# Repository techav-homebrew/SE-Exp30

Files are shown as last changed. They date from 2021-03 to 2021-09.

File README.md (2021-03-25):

# SE-Exp30 Mac SE Accelerator
Minimal 68030 &amp; 68882 accelerator card for the Macintosh SE

This project is not intended to be the fastest or most feature-rich accelerator for the Mac SE. Its primary goal is to be simple and transparent to Mac OS. Without the FPU, it should be able to function as just a faster Mac SE. To make full use of the FPU and the 68030's onboard cache, MacOS may need an init or extension to enable these features and advertise their presence to applications. 

The glue logic is entirely contained in a single 64-macrocel CPLD. Either an Altera EPM7064 or an Atmel ATF1504 will work. It is programmed and compiled for the Altera chip, but tested with the Atmel chip, using the free POF2JED software to convert the compiled configuration to the Atmel format. 

Should the initial design prove successful, future revisions may add cache or RAM on a 32-bit bus to further accelerate the SE. 

## Bill of Materials
Parts count is minimal
- Motorola 68030 CPU (MC68030RC or MC68030RP)
- Motorola 68882 FPU (MC68882RC)
- Microchip/Atmel ATF1504AS-10JU84 (PLLC-84)
- 7x 74'245 buffers (SOIC-20)
- 2x 10uF Electrolyic capacitors (5mm, 2.5mm lead spacing)
- 33x 1uF Ceramic capacitors (0805)
- 16x 4k7 resistors (0805)
- TTL Crystal Oscillator (DIP-8)
- DIN 41612-C 96-pin right-angle connector (male)
- optional 4-pin floppy/Berg power connector

None of the part values are especially critical. The oscillator frequency should match the intended CPU/FPU speed, and the speed grade for the CPLD should be appropriate for the target speed as well. Timing for the CPLD was planned with a 10ns CPLD and 50MHz CPU in mind. As the 68030 CPU and 68882 FPU are no longer produced, it is left to the reader to source these parts and determine the appropriate oscillator frequency to use with whatever parts are available. Processors were originally offered in 16MHz, 20MHz, 25MHz, 33MHz, 40MHz, and 50MHz ratings. It may be necessary to convert the PCB to 4-layers and insert internal power/ground planes to achieve higher clock rates. 

All capacitors on the BOM are included for bypass/filter purposes, so their values are not critical. Lower capacitance isn't recommended, but higher values may certainly be substituted. Similarly, the resistors only serve as pull-ups so their values are also not critical. 

## Power Supply
The Mac SE is rated to provide 7.5W on the 5V rail for PDS cards. This card may exceed that 7.5W rating. Depending on the configuration of the SE model (e.g. presence of a hard drive) and the health of the power supply, a separate 5V power supply may be necessary to power this accelerator. A footprint is provided for a 4-pin floppy (Berg) connector. If an external power supply is used, the jumpers J1, J2, J3 should be left open. If the card will be powered via the PDS slot, these jumpers should be closed, and nothing should be connected to the power connector.

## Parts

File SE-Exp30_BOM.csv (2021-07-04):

Part | Value | Device | Package | Description | Mfg | Mfg Part | Mouser Part
BUFAHI | 74VHCT245 | 74LS245DW | SOIC-20 | Octal BUS TRANSCEIVER, 3-state | Texas Instruments | CY74FCT2245ATSOCT | 595-CY74FCT2245ATOCT
BUFALO | 74VHCT245 | 74LS245DW | SOIC-20 | Octal BUS TRANSCEIVER, 3-state | Texas Instruments | CY74FCT2245ATSOCT | 595-CY74FCT2245ATOCT
BUFAMID | 74VHCT245 | 74LS245DW | SOIC-20 | Octal BUS TRANSCEIVER, 3-state | Texas Instruments | CY74FCT2245ATSOCT | 595-CY74FCT2245ATOCT
BUFC | 74VHCT245 | 74LS245DW | SOIC-20 | Octal BUS TRANSCEIVER, 3-state | Texas Instruments | CY74FCT2245ATSOCT | 595-CY74FCT2245ATOCT
BUFDHI | 74VHCT245 | 74LS245DW | SOIC-20 | Octal BUS TRANSCEIVER, 3-state | Texas Instruments | CY74FCT2245ATSOCT | 595-CY74FCT2245ATOCT
BUFDLO1 | 74VHCT245 | 74LS245DW | SOIC-20 | Octal BUS TRANSCEIVER, 3-state | Texas Instruments | CY74FCT2245ATSOCT | 595-CY74FCT2245ATOCT
BUFDLO2 | 74VHCT245 | 74LS245DW | SOIC-20 | Octal BUS TRANSCEIVER, 3-state | Texas Instruments | CY74FCT2245ATSOCT | 595-CY74FCT2245ATOCT
C1 | 1uF | C-USC0805 | C0805 | CAPACITOR, American symbol | Kemet | C0805C105Z4VACTU | 80-C0805C105Z4V
C2 | 1uF | C-USC0805 | C0805 | CAPACITOR, American symbol | Kemet | C0805C105Z4VACTU | 80-C0805C105Z4V
C3 | 1uF | C-USC0805 | C0805 | CAPACITOR, American symbol | Kemet | C0805C105Z4VACTU | 80-C0805C105Z4V
C4 | 1uF | C-USC0805 | C0805 | CAPACITOR, American symbol | Kemet | C0805C105Z4VACTU | 80-C0805C105Z4V
C5 | 1uF | C-USC0805 | C0805 | CAPACITOR, American symbol | Kemet | C0805C105Z4VACTU | 80-C0805C105Z4V
C6 | 1uF | C-USC0805 | C0805 | CAPACITOR, American symbol | Kemet | C0805C105Z4VACTU | 80-C0805C105Z4V
C7 | 1uF | C-USC0805 | C0805 | CAPACITOR, American symbol | Kemet | C0805C105Z4VACTU | 80-C0805C105Z4V
C8 | 1uF | C-USC0805 | C0805 | CAPACITOR, American symbol | Kemet | C0805C105Z4VACTU | 80-C0805C105Z4V
C9 | 1uF | C-USC0805 | C0805 | CAPACITOR, American symbol | Kemet | C0805C105Z4VACTU | 80-C0805C105Z4V
C10 | 1uF | C-USC0805 | C0805 | CAPACITOR, American symbol | Kemet | C0805C105Z4VACTU | 80-C0805C105Z4V
C11 | 1uF | C-USC0805 | C0805 | CAPACITOR, American symbol | Kemet | C0805C105Z4VACTU | 80-C0805C105Z4V
C12 | 1uF | C-USC0805 | C0805 | CAPACITOR, American symbol | Kemet | C0805C105Z4VACTU | 80-C0805C105Z4V
C13 | 1uF | C-USC0805 | C0805 | CAPACITOR, American symbol | Kemet | C0805C105Z4VACTU | 80-C0805C105Z4V
C14 | 1uF | C-USC0805 | C0805 | CAPACITOR, American symbol | Kemet | C0805C105Z4VACTU | 80-C0805C105Z4V
C15 | 1uF | C-USC0805 | C0805 | CAPACITOR, American symbol | Kemet | C0805C105Z4VACTU | 80-C0805C105Z4V
C16 | 1uF | C-USC0805 | C0805 | CAPACITOR, American symbol | Kemet | C0805C105Z4VACTU | 80-C0805C105Z4V
C17 | 1uF | C-USC0805 | C0805 | CAPACITOR, American symbol | Kemet | C0805C105Z4VACTU | 80-C0805C105Z4V
C18 | 1uF | C-USC0805 | C0805 | CAPACITOR, American symbol | Kemet | C0805C105Z4VACTU | 80-C0805C105Z4V
C19 | 1uF | C-USC0805 | C0805 | CAPACITOR, American symbol | Kemet | C0805C105Z4VACTU | 80-C0805C105Z4V
C20 | 1uF | C-USC0805 | C0805 | CAPACITOR, American symbol | Kemet | C0805C105Z4VACTU | 80-C0805C105Z4V
C21 | 1uF | C-USC0805 | C0805 | CAPACITOR, American symbol | Kemet | C0805C105Z4VACTU | 80-C0805C105Z4V
C22 | 1uF | C-USC0805 | C0805 | CAPACITOR, American symbol | Kemet | C0805C105Z4VACTU | 80-C0805C105Z4V
C23 | 1uF | C-USC0805 | C0805 | CAPACITOR, American symbol | Kemet | C0805C105Z4VACTU | 80-C0805C105Z4V
C24 | 1uF | C-USC0805 | C0805 | CAPACITOR, American symbol | Kemet | C0805C105Z4VACTU | 80-C0805C105Z4V
C25 | 1uF | C-USC0805 | C0805 | CAPACITOR, American symbol | Kemet | C0805C105Z4VACTU | 80-C0805C105Z4V
C26 | 1uF | C-USC0805 | C0805 | CAPACITOR, American symbol | Kemet | C0805C105Z4VACTU | 80-C0805C105Z4V
C27 | 10uF | CPOL-USE2.5-5 | E2,5-5 | POLARIZED CAPACITOR, American symbol | Panasonic | ECA-1EM100I | 667-ECA-1EM100I
C28 | 10uF | CPOL-USE2.5-5 | E2,5-5 | POLARIZED CAPACITOR, American symbol | Panasonic | ECA-1EM100I | 667-ECA-1EM100I
C29 | 1uF | C-USC0805 | C0805 | CAPACITOR, American symbol | Kemet | C0805C105Z4VACTU | 80-C0805C105Z4V
C30 | 1uF | C-USC0805 | C0805 | CAPACITOR, American symbol | Kemet | C0805C105Z4VACTU | 80-C0805C105Z4V
C31 | 1uF | C-USC0805 | C0805 | CAPACITOR, American symbol | Kemet | C0805C105Z4VACTU | 80-C0805C105Z4V
C32 | 1uF | C-USC0805 | C0805 | CAPACITOR, American symbol | Kemet | C0805C105Z4VACTU | 80-C0805C105Z4V
C33 | 1uF | C-USC0805 | C0805 | CAPACITOR, American symbol | Kemet | C0805C105Z4VACTU | 80-C0805C105Z4V
C34 | 1uF | C-USC0805 | C0805 | CAPACITOR, American symbol | Kemet | C0805C105Z4VACTU | 80-C0805C105Z4V
C35 | 1uF | C-USC0805 | C0805 | CAPACITOR, American symbol | Kemet | C0805C105Z4VACTU | 80-C0805C105Z4V
CLOCK |  | QG5460 | DIL08S | CRYSTAL RESONATOR
CPU | 68030 | MC68030RC | MPGA128 | 68xxx PROCESSOR | Motorola | MC68030RCxx
FPU | 68882 | MC68881RC | MPGA68 | 68xxx PROCESSOR | Motorola | MC68882RCxx
JP1 |  | JP1Q | JP1 | JUMPER
JP2 |  | JP1Q | JP1 | JUMPER
JP3 |  | JP1Q | JP1 | JUMPER
PASTE | ATF1504AS | EPM7128-J84S | S84 | EPM70128 | Microchip | ATF1504AS-10JU84 | 556-AF1504AS10JU84
POWER |  | L04P | L04P | AMP MT CONNECTOR | TE Connectivity | 171826-4 | 571-1718264
R1 | 4k7 | R-US_R0805 | R0805 | RESISTOR, American symbol | Vishay | CRCW08054K70JNEAC | 71-CRCW08054K70JNEAC
R2 | 4k7 | R-US_R0805 | R0805 | RESISTOR, American symbol | Vishay | CRCW08054K70JNEAC | 71-CRCW08054K70JNEAC
R3 | 4k7 | R-US_R0805 | R0805 | RESISTOR, American symbol | Vishay | CRCW08054K70JNEAC | 71-CRCW08054K70JNEAC
R4 | 4k7 | R-US_R0805 | R0805 | RESISTOR, American symbol | Vishay | CRCW08054K70JNEAC | 71-CRCW08054K70JNEAC
R5 | 4k7 | R-US_R0805 | R0805 | RESISTOR, American symbol | Vishay | CRCW08054K70JNEAC | 71-CRCW08054K70JNEAC
R6 | 4k7 | R-US_R0805 | R0805 | RESISTOR, American symbol | Vishay | CRCW08054K70JNEAC | 71-CRCW08054K70JNEAC
R7 | 4k7 | R-US_R0805 | R0805 | RESISTOR, American symbol | Vishay | CRCW08054K70JNEAC | 71-CRCW08054K70JNEAC
R8 | 4k7 | R-US_R0805 | R0805 | RESISTOR, American symbol | Vishay | CRCW08054K70JNEAC | 71-CRCW08054K70JNEAC
R9 | 4k7 | R-US_R0805 | R0805 | RESISTOR, American symbol | Vishay | CRCW08054K70JNEAC | 71-CRCW08054K70JNEAC
R10 | 4k7 | R-US_R0805 | R0805 | RESISTOR, American symbol | Vishay | CRCW08054K70JNEAC | 71-CRCW08054K70JNEAC
R11 | 4k7 | R-US_R0805 | R0805 | RESISTOR, American symbol | Vishay | CRCW08054K70JNEAC | 71-CRCW08054K70JNEAC
R12 | 4k7 | R-US_R0805 | R0805 | RESISTOR, American symbol | Vishay | CRCW08054K70JNEAC | 71-CRCW08054K70JNEAC
R13 | 4k7 | R-US_R0805 | R0805 | RESISTOR, American symbol | Vishay | CRCW08054K70JNEAC | 71-CRCW08054K70JNEAC
R14 | 4k7 | R-US_R0805 | R0805 | RESISTOR, American symbol | Vishay | CRCW08054K70JNEAC | 71-CRCW08054K70JNEAC
R15 | 4k7 | R-US_R0805 | R0805 | RESISTOR, American symbol | Vishay | CRCW08054K70JNEAC | 71-CRCW08054K70JNEAC
R16 | 4k7 | R-US_R0805 | R0805 | RESISTOR, American symbol | Vishay | CRCW08054K70JNEAC | 71-CRCW08054K70JNEAC
X1 | MABC96LP | MABC96LP | MABC96LP | CONNECTOR male, 96 pins, type C, rows ABC, grid 2.54 mm with mounting clip | TE Connectivity | 650473-5 | 571-6504735

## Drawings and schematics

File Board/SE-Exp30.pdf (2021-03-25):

CLK E01 | D0 K13 | D1 K12 | D2 L13 | D3 M13 | D4 L12 | D5 K11 | D6 M12 | D7 L11 | D8 N13 | D9 M11 | D10 L10 | D11 N12 | D12 M10 | D13 N11 | D14 M09 | D15 N10 | D16 N09 | D17 M08 | D18 N08 | D19 N07 | D20 M07 | D21 N06 | D22 M06 | D23 N05 | D24 M05 | D25 N04 | D26 N03 | D27 M04 | D28 N02 | D29 M03 | D30 L04 | D31 N01
A0 | H03 A1 | K01 A2 | H02 A3 | J01 A4 | G02 AS H01 | CLK C02 | CS J03 | D0 A03 | D1 A04 | D2 B05 | D3 A05 | D4 A06 | D5 B06 | D6 A07 | D7 A08 | D8 A09 | D9 C08 | D10 B09 | D11 B10 | D12 D09 | D13 C09 | D14 C10 | D15 D10 | D16 F10 | D17 F09 | D18 G10 | D19 H10 | D20 G09 | D21 J10 | D22 K10 | D23 J09 | D24 K09 | D25 J07 | D26 K08 | D27 K07 | D28 J06 | D29 K06 | D30 K05 | D31 J05

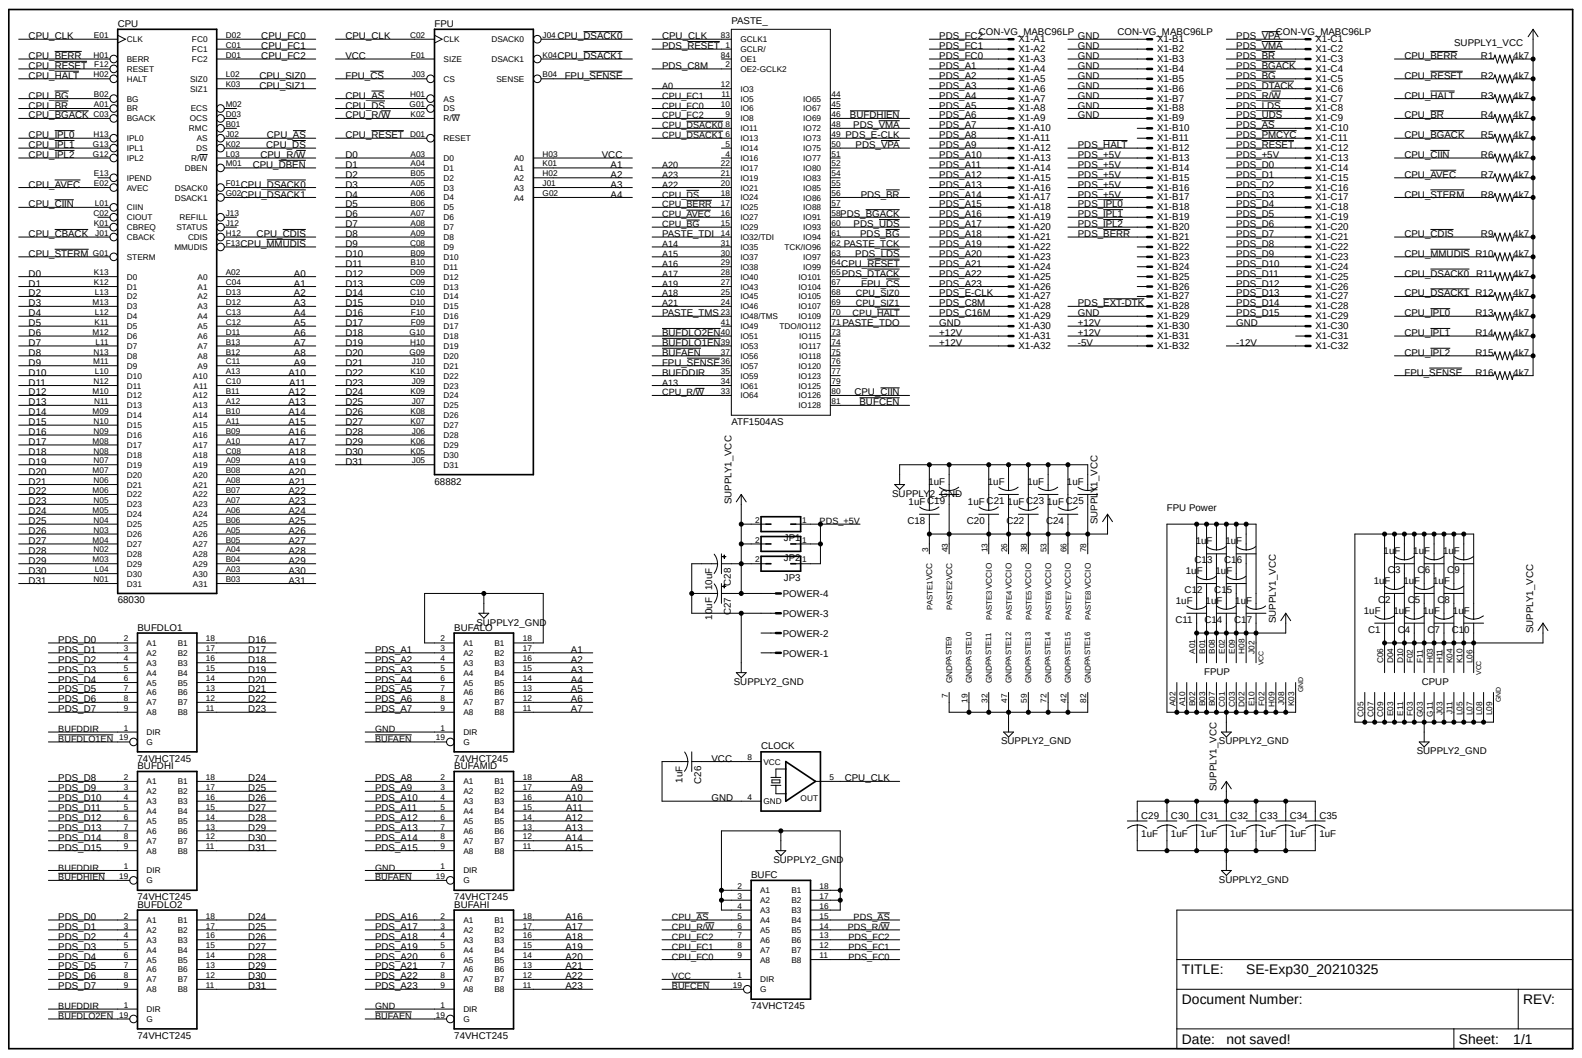
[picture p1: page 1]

3 PASTE1VCC 43 PASTE2VCCIO 13 PASTE3 VCCIO 26 PASTE4 VCCIO 38 PASTE5 VCCIO 53 PASTE6 VCCIO 66 PASTE7 VCCIO 78 PASTE8 GND

7 PASTE9 GND 19 PASTE10 GND 32 PASTE11 GND 47 PASTE12 GND 59 PASTE13 GND 72 PASTE14 GND 42 PASTE15 GND 82 PASTE16 A1 2 A2 3 A3 4 A4 5 A5 6 A6 7 A7 8 A8 9 B1 18 B2 17 B3 16 B4 15 B5 14 B6 13 B7 12 B8 11 DIR 1 G

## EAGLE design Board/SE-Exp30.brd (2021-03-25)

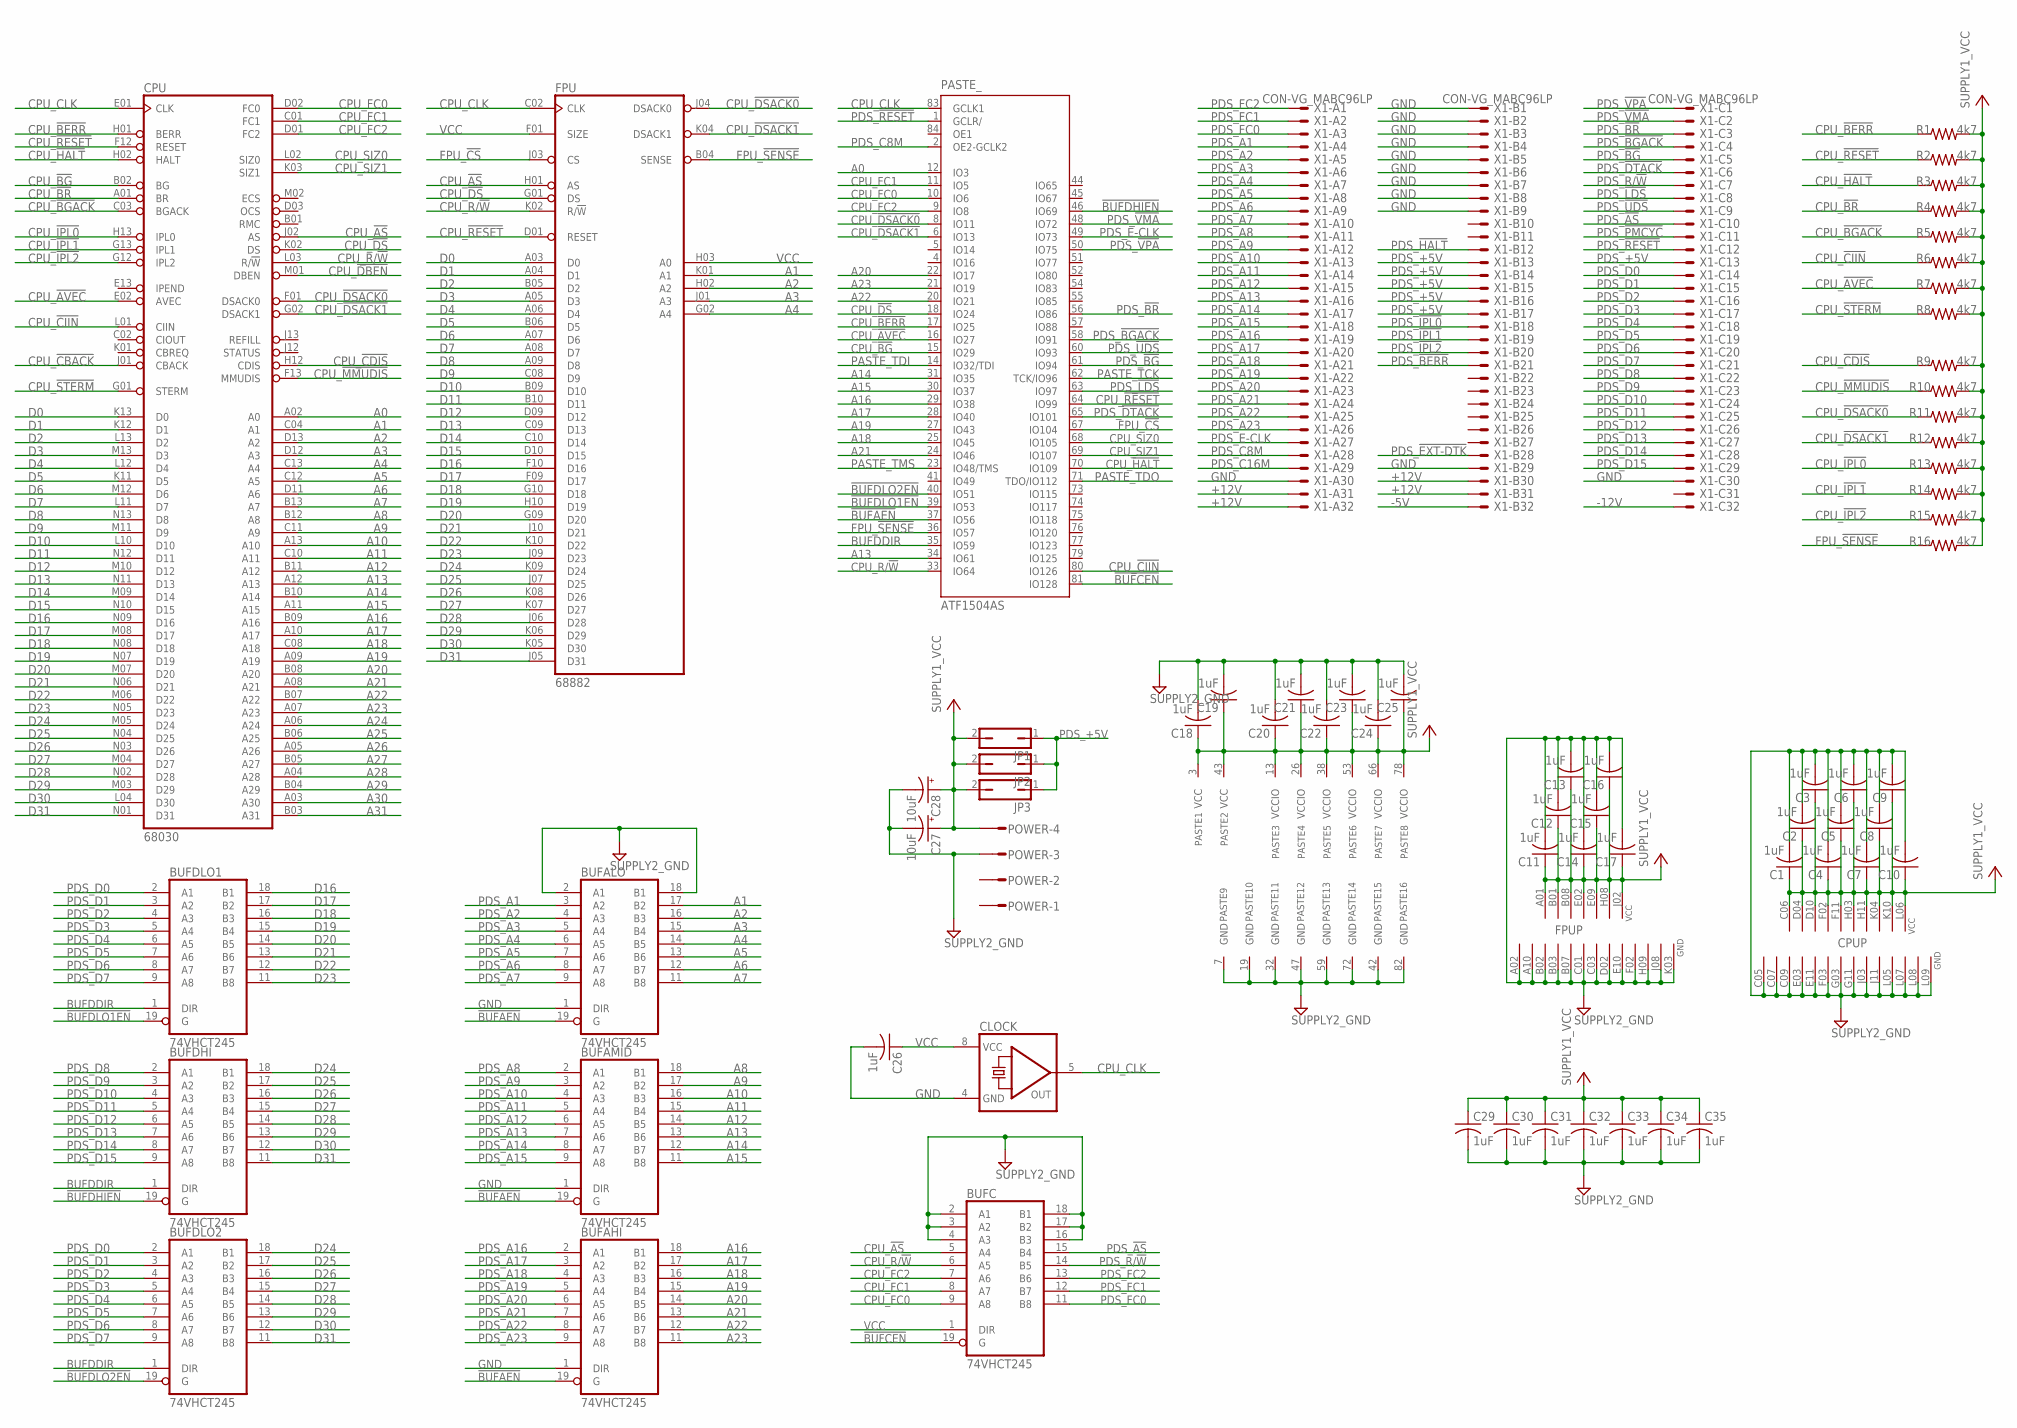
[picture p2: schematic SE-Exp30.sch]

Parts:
BUFAHI: 74VHCT245; 74XX-US_SO20W
BUFALO: 74VHCT245; 74XX-US_SO20W
BUFAMID: 74VHCT245; 74XX-US_SO20W
BUFC: 74VHCT245; 74XX-US_SO20W
BUFDHI: 74VHCT245; 74XX-US_SO20W
BUFDLO1, BUFDLO2: 74VHCT245; 74XX-US_SO20W
C1, C2, C3, C4, C5, C6, C7, C8, C9, C10, C11, C12, C13, C14, C15, C16, C17, C18, C19, C20, C21, C22, C23, C24, C25, C26, C29, C30, C31, C32, C33, C34, C35: 1uF; RCL_C0805
C27, C28: 10uF; RCL_E2,5-5
CLOCK: CRYSTAL_QG5460; CRYSTAL_DIL08S
CPU: 68030; MICRO-MC68000_MPGA128
FPU: 68882; MICRO-MC68000_MPGA68
JP1, JP2, JP3: JUMPER_JP1Q; JUMPER_JP1
PASTE: ATF1504AS; SE-EXP30_S84
POWER: CON-AMP-MT_L04P
R1, R2, R3, R4, R5, R6, R7, R8, R9, R10, R11, R12, R13, R14, R15, R16: 4k7; RCL_R0805
X1: CON-VG_MABC96LP

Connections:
!BUFAEN: BUFAHI.19 (G), BUFALO.19 (G), BUFAMID.19 (G), PASTE.37 (IO56)
!BUFCEN: BUFC.19 (G), PASTE.81 (IO128)
!BUFDHIEN: BUFDHI.19 (G), PASTE.46 (IO69)
!BUFDLO1EN: BUFDLO1.19 (G), PASTE.39 (IO53)
!BUFDLO2EN: BUFDLO2.19 (G), PASTE.40 (IO51)
+12V: X1.A31, X1.A32, X1.B30, X1.B31
-5V: X1.B32
-12V: X1.C32
A0: CPU.A02 (A0), PASTE.12 (IO3)
A1: BUFALO.17 (B2), CPU.C04 (A1), FPU.K01 (A1)
A2: BUFALO.16 (B3), CPU.D13 (A2), FPU.H02 (A2)
A3: BUFALO.15 (B4), CPU.D12 (A3), FPU.J01 (A3)
A4: BUFALO.14 (B5), CPU.C13 (A4), FPU.G02 (A4)
A5: BUFALO.13 (B6), CPU.C12 (A5)
A6: BUFALO.12 (B7), CPU.D11 (A6)
A7: BUFALO.11 (B8), CPU.B13 (A7)
A8: BUFAMID.18 (B1), CPU.B12 (A8)
A9: BUFAMID.17 (B2), CPU.C11 (A9)
A10: BUFAMID.16 (B3), CPU.A13 (A10)
A11: BUFAMID.15 (B4), CPU.C10 (A11)
A12: BUFAMID.14 (B5), CPU.B11 (A12)
A13: BUFAMID.13 (B6), CPU.A12 (A13), PASTE.34 (IO61)
A14: BUFAMID.12 (B7), CPU.B10 (A14), PASTE.31 (IO35)
A15: BUFAMID.11 (B8), CPU.A11 (A15), PASTE.30 (IO37)
A16: BUFAHI.18 (B1), CPU.B09 (A16), PASTE.29 (IO38)
A17: BUFAHI.17 (B2), CPU.A10 (A17), PASTE.28 (IO40)
A18: BUFAHI.16 (B3), CPU.C08 (A18), PASTE.25 (IO45)
A19: BUFAHI.15 (B4), CPU.A09 (A19), PASTE.27 (IO43)
A20: BUFAHI.14 (B5), CPU.B08 (A20), PASTE.22 (IO17)
A21: BUFAHI.13 (B6), CPU.A08 (A21), PASTE.24 (IO46)
A22: BUFAHI.12 (B7), CPU.B07 (A22), PASTE.20 (IO21)
A23: BUFAHI.11 (B8), CPU.A07 (A23), PASTE.21 (IO19)
A24: CPU.A06 (A24)
A25: CPU.B06 (A25)
A26: CPU.A05 (A26)
A27: CPU.B05 (A27)
A28: CPU.A04 (A28)
A29: CPU.B04 (A29)
A30: CPU.A03 (A30)
A31: CPU.B03 (A31)
BUFDDIR: BUFDHI.1 (DIR), BUFDLO1.1 (DIR), BUFDLO2.1 (DIR), PASTE.35 (IO59)
CPU_!AS: BUFC.5 (A4), CPU.J02 (AS), FPU.H01 (AS)
CPU_!AVEC: CPU.E02 (AVEC), PASTE.16 (IO27), R7.1
CPU_!BERR: CPU.H01 (BERR), PASTE.17 (IO25), R1.1
CPU_!BG: CPU.B02 (BG), PASTE.15 (IO29)
CPU_!BGACK: CPU.C03 (BGACK), R5.1
CPU_!BR: CPU.A01 (BR), R4.1
CPU_!CBACK: CPU.J01 (CBACK)
CPU_!CDIS: CPU.H12 (CDIS), R9.1
CPU_!CIIN: CPU.L01 (CIIN), PASTE.80 (IO126), R6.1
CPU_!DBEN: CPU.M01 (DBEN)
CPU_!DS: CPU.K02 (DS), FPU.G01 (DS), PASTE.18 (IO24)
CPU_!DSACK0: CPU.F01 (DSACK0), FPU.J04 (DSACK0), PASTE.8 (IO11), R11.1
CPU_!DSACK1: CPU.G02 (DSACK1), FPU.K04 (DSACK1), PASTE.6 (IO13), R12.1
CPU_!HALT: CPU.H02 (HALT), PASTE.70 (IO109), R3.1
CPU_!IPL0: CPU.H13 (IPL0), R13.1
CPU_!IPL1: CPU.G13 (IPL1), R14.1
CPU_!IPL2: CPU.G12 (IPL2), R15.1
CPU_!MMUDIS: CPU.F13 (MMUDIS), R10.1
CPU_!RESET: CPU.F12 (RESET), FPU.D01 (RESET), PASTE.64 (IO99), R2.1
CPU_!STERM: CPU.G01 (STERM), R8.1
CPU_CLK: CLOCK.5 (OUT), CPU.E01 (CLK), FPU.C02 (CLK), PASTE.83 (GCLK1)
CPU_FC0: BUFC.9 (A8), CPU.D02 (FC0), PASTE.10 (IO6)
CPU_FC1: BUFC.8 (A7), CPU.C01 (FC1), PASTE.11 (IO5)
CPU_FC2: BUFC.7 (A6), CPU.D01 (FC2), PASTE.9 (IO8)
CPU_R/!W: BUFC.6 (A5), CPU.L03 (R/!W), FPU.K02 (R/!W), PASTE.33 (IO64)
CPU_SIZ0: CPU.L02 (SIZ0), PASTE.68 (IO105)
CPU_SIZ1: CPU.K03 (SIZ1), PASTE.69 (IO107)
D0: CPU.K13 (D0), FPU.A03 (D0)
D1: CPU.K12 (D1), FPU.A04 (D1)
D2: CPU.L13 (D2), FPU.B05 (D2)
D3: CPU.M13 (D3), FPU.A05 (D3)
D4: CPU.L12 (D4), FPU.A06 (D4)
D5: CPU.K11 (D5), FPU.B06 (D5)
D6: CPU.M12 (D6), FPU.A07 (D6)
D7: CPU.L11 (D7), FPU.A08 (D7)
D8: CPU.N13 (D8), FPU.A09 (D8)
D9: CPU.M11 (D9), FPU.C08 (D9)
D10: CPU.L10 (D10), FPU.B09 (D10)
D11: CPU.N12 (D11), FPU.B10 (D11)
D12: CPU.M10 (D12), FPU.D09 (D12)
D13: CPU.N11 (D13), FPU.C09 (D13)
D14: CPU.M09 (D14), FPU.C10 (D14)
D15: CPU.N10 (D15), FPU.D10 (D15)
D16: BUFDLO1.18 (B1), CPU.N09 (D16), FPU.F10 (D16)
D17: BUFDLO1.17 (B2), CPU.M08 (D17), FPU.F09 (D17)
D18: BUFDLO1.16 (B3), CPU.N08 (D18), FPU.G10 (D18)
D19: BUFDLO1.15 (B4), CPU.N07 (D19), FPU.H10 (D19)
D20: BUFDLO1.14 (B5), CPU.M07 (D20), FPU.G09 (D20)
D21: BUFDLO1.13 (B6), CPU.N06 (D21), FPU.J10 (D21)
D22: BUFDLO1.12 (B7), CPU.M06 (D22), FPU.K10 (D22)
D23: BUFDLO1.11 (B8), CPU.N05 (D23), FPU.J09 (D23)
D24: BUFDHI.18 (B1), BUFDLO2.18 (B1), CPU.M05 (D24), FPU.K09 (D24)
D25: BUFDHI.17 (B2), BUFDLO2.17 (B2), CPU.N04 (D25), FPU.J07 (D25)
D26: BUFDHI.16 (B3), BUFDLO2.16 (B3), CPU.N03 (D26), FPU.K08 (D26)
D27: BUFDHI.15 (B4), BUFDLO2.15 (B4), CPU.M04 (D27), FPU.K07 (D27)
D28: BUFDHI.14 (B5), BUFDLO2.14 (B5), CPU.N02 (D28), FPU.J06 (D28)
D29: BUFDHI.13 (B6), BUFDLO2.13 (B6), CPU.M03 (D29), FPU.K06 (D29)
D30: BUFDHI.12 (B7), BUFDLO2.12 (B7), CPU.L04 (D30), FPU.K05 (D30)
D31: BUFDHI.11 (B8), BUFDLO2.11 (B8), CPU.N01 (D31), FPU.J05 (D31)
FPU_!CS: FPU.J03 (CS), PASTE.67 (IO104)
FPU_!SENSE: FPU.B04 (SENSE), PASTE.36 (IO57), R16.1
GND: BUFAHI.1 (DIR), BUFAHI.10 (GND), BUFALO.1 (DIR), BUFALO.2 (A1), BUFALO.10 (GND), BUFALO.18 (B1), BUFAMID.1 (DIR), BUFAMID.10 (GND), BUFC.2 (A1), BUFC.3 (A2), BUFC.4 (A3), BUFC.10 (GND), BUFC.16 (B3), BUFC.17 (B2), BUFC.18 (B1), BUFDHI.10 (GND), BUFDLO1.10 (GND), BUFDLO2.10 (GND), C1.2, C2.2, C3.2, C4.2, C5.2, C6.2, C7.2, C8.2, C9.2, C10.2, C11.2, C12.2, C13.2, C14.2, C15.2, C16.2, C17.2, C18.2, C19.2, C20.2, C21.2, C22.2, C23.2, C24.2, C25.2, C26.2, C27.-, C28.-, C29.2, C30.2, C31.2, C32.2, C33.2, C34.2, C35.2, CLOCK.4 (GND), CPU.C05 (GND), CPU.C07 (GND), CPU.C09 (GND), CPU.E03 (GND), CPU.E11 (GND), CPU.F03 (GND), CPU.G03 (GND), CPU.G11 (GND), CPU.J03 (GND), CPU.J11 (GND), CPU.L05 (GND), CPU.L07 (GND), CPU.L08 (GND), CPU.L09 (GND), FPU.A02 (GND), FPU.A10 (GND), FPU.B02 (GND), FPU.B03 (GND), FPU.B07 (GND), FPU.C01 (GND), FPU.C03 (GND), FPU.D02 (GND), FPU.E10 (GND), FPU.F02 (GND), FPU.H09 (GND), FPU.J08 (GND), FPU.K03 (GND), PASTE.7 (GND), PASTE.19 (GND), PASTE.32 (GND), PASTE.42 (GND), PASTE.47 (GND), PASTE.59 (GND), PASTE.72 (GND), PASTE.82 (GND), POWER.3, X1.A30, X1.B1, X1.B2, X1.B3, X1.B4, X1.B5, X1.B6, X1.B7, X1.B8, X1.B9, X1.B29, X1.C30
PASTE_TCK: PASTE.62 (TCK/IO96)
PASTE_TDI: PASTE.14 (IO32/TDI)
PASTE_TDO: PASTE.71 (TDO/IO112)
PASTE_TMS: PASTE.23 (IO48/TMS)
PDS_!AS: BUFC.15 (B4), X1.C10
PDS_!BERR: X1.B21
PDS_!BG: PASTE.61 (IO94), X1.C5
PDS_!BGACK: PASTE.58 (IO91), X1.C4
PDS_!BR: PASTE.56 (IO86), X1.C3
PDS_!DTACK: PASTE.65 (IO101), X1.C6
PDS_!EXT-DTK: X1.B28
PDS_!HALT: X1.B12
PDS_!IPL0: X1.B18
PDS_!IPL1: X1.B19
PDS_!IPL2: X1.B20
PDS_!LDS: PASTE.63 (IO97), X1.C8
PDS_!PMCYC: X1.C11
PDS_!RESET: PASTE.1 (GCLR/), X1.C12
PDS_!UDS: PASTE.60 (IO93), X1.C9
PDS_!VMA: PASTE.48 (IO72), X1.C2
PDS_!VPA: PASTE.50 (IO75), X1.C1
PDS_+5V: JP1.1, JP2.1, JP3.1, X1.B13, X1.B14, X1.B15, X1.B16, X1.B17, X1.C13
PDS_A1: BUFALO.3 (A2), X1.A4
PDS_A2: BUFALO.4 (A3), X1.A5
PDS_A3: BUFALO.5 (A4), X1.A6
PDS_A4: BUFALO.6 (A5), X1.A7
PDS_A5: BUFALO.7 (A6), X1.A8
PDS_A6: BUFALO.8 (A7), X1.A9
PDS_A7: BUFALO.9 (A8), X1.A10
PDS_A8: BUFAMID.2 (A1), X1.A11
PDS_A9: BUFAMID.3 (A2), X1.A12
PDS_A10: BUFAMID.4 (A3), X1.A13
PDS_A11: BUFAMID.5 (A4), X1.A14
PDS_A12: BUFAMID.6 (A5), X1.A15
PDS_A13: BUFAMID.7 (A6), X1.A16
PDS_A14: BUFAMID.8 (A7), X1.A17
PDS_A15: BUFAMID.9 (A8), X1.A18
PDS_A16: BUFAHI.2 (A1), X1.A19
PDS_A17: BUFAHI.3 (A2), X1.A20
PDS_A18: BUFAHI.4 (A3), X1.A21
PDS_A19: BUFAHI.5 (A4), X1.A22
PDS_A20: BUFAHI.6 (A5), X1.A23
PDS_A21: BUFAHI.7 (A6), X1.A24
PDS_A22: BUFAHI.8 (A7), X1.A25
PDS_A23: BUFAHI.9 (A8), X1.A26
PDS_C8M: PASTE.2 (OE2-GCLK2), X1.A28
PDS_C16M: X1.A29
PDS_D0: BUFDLO1.2 (A1), BUFDLO2.2 (A1), X1.C14
PDS_D1: BUFDLO1.3 (A2), BUFDLO2.3 (A2), X1.C15
PDS_D2: BUFDLO1.4 (A3), BUFDLO2.4 (A3), X1.C16
PDS_D3: BUFDLO1.5 (A4), BUFDLO2.5 (A4), X1.C17
PDS_D4: BUFDLO1.6 (A5), BUFDLO2.6 (A5), X1.C18
PDS_D5: BUFDLO1.7 (A6), BUFDLO2.7 (A6), X1.C19
PDS_D6: BUFDLO1.8 (A7), BUFDLO2.8 (A7), X1.C20
PDS_D7: BUFDLO1.9 (A8), BUFDLO2.9 (A8), X1.C21
PDS_D8: BUFDHI.2 (A1), X1.C22
PDS_D9: BUFDHI.3 (A2), X1.C23
PDS_D10: BUFDHI.4 (A3), X1.C24
PDS_D11: BUFDHI.5 (A4), X1.C25
PDS_D12: BUFDHI.6 (A5), X1.C26
PDS_D13: BUFDHI.7 (A6), X1.C27
PDS_D14: BUFDHI.8 (A7), X1.C28
PDS_D15: BUFDHI.9 (A8), X1.C29
PDS_E-CLK: PASTE.49 (IO73), X1.A27
PDS_FC0: BUFC.11 (B8), X1.A3
PDS_FC1: BUFC.12 (B7), X1.A2
PDS_FC2: BUFC.13 (B6), X1.A1
PDS_R/!W: BUFC.14 (B5), X1.C7
VCC: BUFAHI.20 (VCC), BUFALO.20 (VCC), BUFAMID.20 (VCC), BUFC.1 (DIR), BUFC.20 (VCC), BUFDHI.20 (VCC), BUFDLO1.20 (VCC), BUFDLO2.20 (VCC), C1.1, C2.1, C3.1, C4.1, C5.1, C6.1, C7.1, C8.1, C9.1, C10.1, C11.1, C12.1, C13.1, C14.1, C15.1, C16.1, C17.1, C18.1, C19.1, C20.1, C21.1, C22.1, C23.1, C24.1, C25.1, C26.1, C27.+, C28.+, C29.1, C30.1, C31.1, C32.1, C33.1, C34.1, C35.1, CLOCK.8 (VCC), CPU.C06 (VCC), CPU.D04 (VCC), CPU.D10 (VCC), CPU.F02 (VCC), CPU.F11 (VCC), CPU.H03 (VCC), CPU.H11 (VCC), CPU.K04 (VCC), CPU.K10 (VCC), CPU.L06 (VCC), FPU.A01 (VCC), FPU.B01 (VCC), FPU.B08 (VCC), FPU.E02 (VCC), FPU.E09 (VCC), FPU.F01 (SIZE), FPU.H03 (A0), FPU.H08 (VCC), FPU.J02 (VCC), JP1.2, JP2.2, JP3.2, PASTE.3 (VCC), PASTE.13 (VCCIO), PASTE.26 (VCCIO), PASTE.38 (VCCIO), PASTE.43 (VCC), PASTE.53 (VCCIO), PASTE.66 (VCCIO), PASTE.78 (VCCIO), POWER.4, R1.2, R2.2, R3.2, R4.2, R5.2, R6.2, R7.2, R8.2, R9.2, R10.2, R11.2, R12.2, R13.2, R14.2, R15.2, R16.2

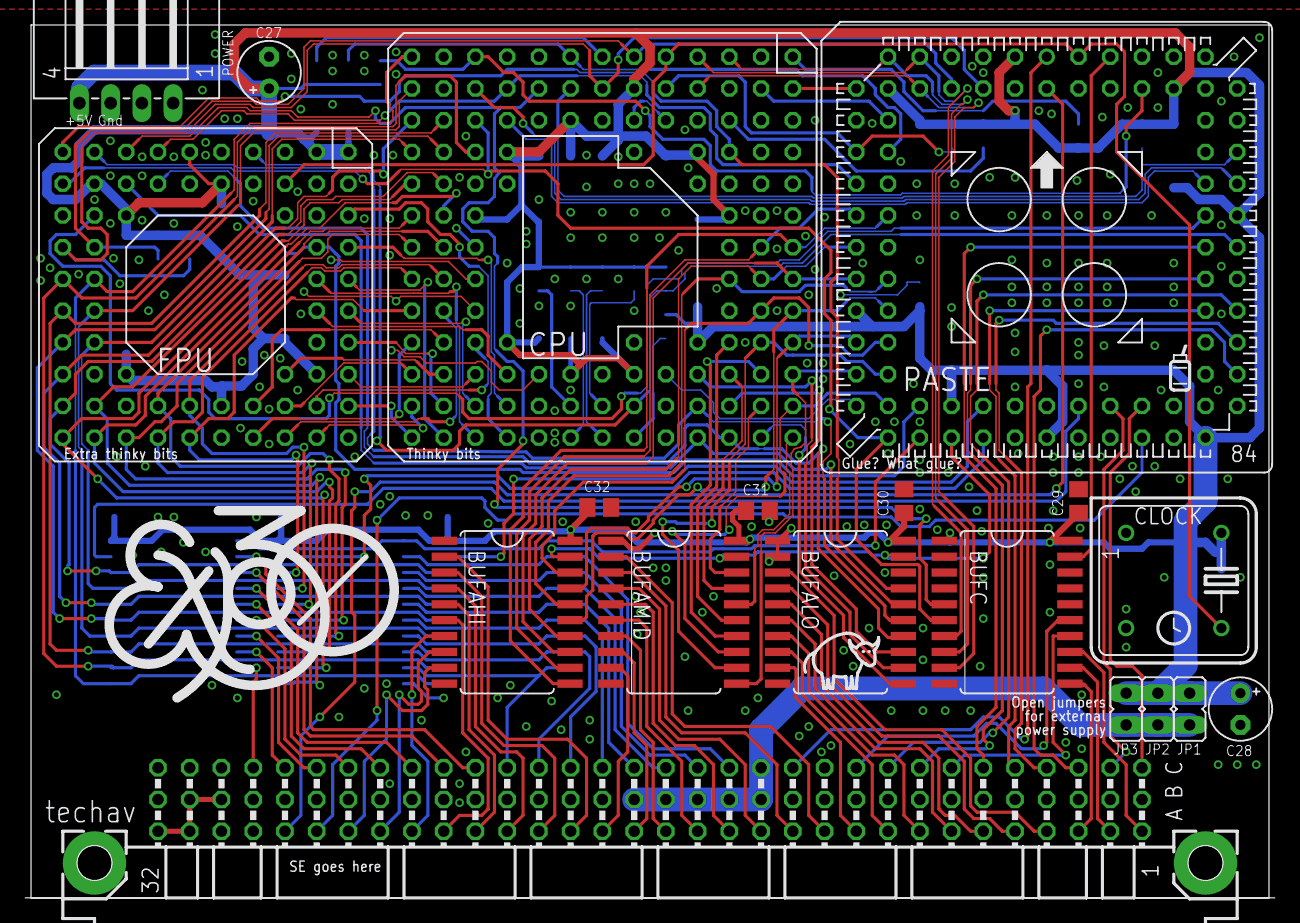
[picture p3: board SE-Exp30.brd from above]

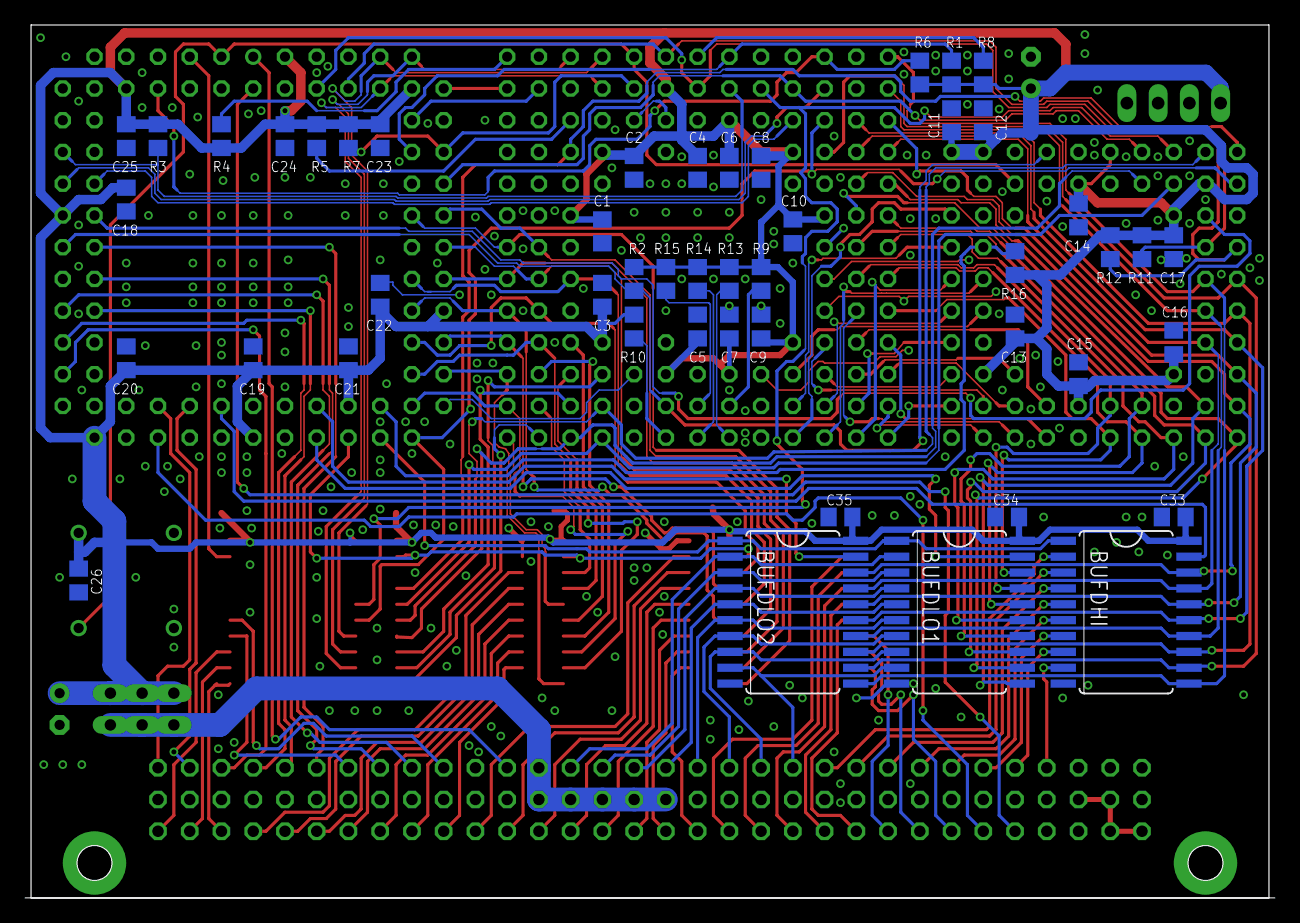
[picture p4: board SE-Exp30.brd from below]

Board: 2 copper layers, 99.1 x 69.8 mm, 68 parts (48 on the bottom side), 148 nets.

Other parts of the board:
U$1: BUFFALO

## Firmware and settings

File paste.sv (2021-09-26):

/******************************************************************************
 * SE-Exp30 MacSE Accelerator
 * techav
 * 2021-03-20
 * Processor Accelerator System Translation Engine
 ******************************************************************************
 * Handles all logic to translate the Mac SE 68000 PDS bus to the 68030 bus as 
 * well as additional logic for interfacing with the 68882 FPU.
 *****************************************************************************/

module paste (
    inout wire          ncpuReset,          // 68030 reset signal (tristate)
    inout wire          ncpuHalt,           // 68030 halt signal (tristate)
    input wire          ncpuDS,             // 68030 data strobe signal
    input wire          ncpuAS,             // 68030 address strobe signal
    inout wire          ncpuDsack0,         // 68030 DS Ack 0 signal
    inout wire          ncpuDsack1,         // 68030 DS Ack 1 signal
    input wire          cpuSize0,           // 68030 Size 0 signal
    input wire          cpuSize1,           // 68030 Size 1 signal
    input wire          cpuA0,              // 68030 Address 0 signal
    input logic [23:20] cpuAddrHi,          // 68030 Address Hi (16MB) signals
    input logic [19:13] cpuAddrMid,         // 68030 Address Mid (FPU decode) signals
    output wire         ncpuAvec,           // 68030 Autovector request signal
    input logic [2:0]   cpuFC,              // 68030 Function Code signals
    input wire          cpuClock,           // 68030 Primary CPU Clock signal
    input wire          cpuRnW,             // 68030 Read/Write signal
    input wire          ncpuBG,             // 68030 Bus Grant signal
    inout wire          ncpuBerr,           // 68030 Bus Error signal
    inout wire          ncpuCiin,           // 68030 Cache Inhibit signal
    input wire          npdsReset,          // PDS Reset signal
    inout wire          npdsLds,            // PDS Lower Data Strobe signal
    inout wire          npdsUds,            // PDS Upper Data Strobe signal
    inout wire          npdsAs,             // PDS Address Strobe signal
    input wire          npdsDtack,          // PDS Data Xfer Ack signal
    input wire          npdsBg,             // PDS Bus Grant signal
    output wire         npdsBGack,          // PDS Bus Grant Ack signal
    output wire         npdsBr,             // PDS Bus Request signal
    inout wire          npdsVma,            // PDS Valid Memory Addr signal
    input wire          npdsVpa,            // PDS Valid Peripheral Addr signal
    input wire          pdsC8m,             // PDS 8MHz System Clock signal
    input wire          pdsClockE,          // PDS 800kHz 6800 bus E clock
    output wire         nbufDhiEn,          // Data buffer CPU[31:24] <=> PDS[15:8]
    output wire         nbufDlo1En,         // Data buffer CPU[23:16] <=> PDS[7:0]
    output wire         nbufDlo2En,         // Data buffer CPU[31:24] <=> PDS[7:0]
    output wire         bufDDir,            // Data buffer direction
    output wire         nbufCEn,            // Control signal buffer enable
    output wire         nbufAEn,            // Address buffer enable
    input wire          nfpuSense,          // FPU Presence Detect signal
    output wire         nfpuCe              // FPU Chip Select signal
);

// define state machine states
parameter
    S0  =   0,
    S1  =   1,
    S2  =   2,
    S3  =   3,
    S4  =   4,
    S5  =   5,
    S6  =   6,
    S7  =   7,
    S8  =   8;

logic [3:0] busState;           // state machine for 68000 bus
logic [1:0] termState;          // state machine for 68030 bus termination
logic [1:0] resetgenState;      // state machine for nCpuReset generator
logic [1:0] cycleEndState;      // state machine for 68030 bus cycle end monitor

wire nUD, nLD;                  // intermediate data strobe signals

// 68000 bus state machine
// synchronous to 8MHz 68000 clock
always @(posedge pdsC8m or negedge npdsReset) begin
    if(npdsReset == 0) busState <= S0;
    else begin
        case(busState) 
            S0 : begin
                // idle state, wait for cpu to begin bus cycle
                if(ncpuAS == 0) busState <= S1;
                else busState <= S0;
            end
            S1 : begin
                // 68000 bus cycle state 2/3
                // progress immediately
                busState <= S2;
            end
            S2 : begin
                // 68000 bus cycle state 4/5
                // wait for PDS DTACK or PDS VPA
                if(npdsDtack == 0) busState <= S3;
                else if(npdsVpa == 0) busState <= S4;
                else busState <= S2;
            end
            S3 : begin
                // 68000 bus cycle state 6/7
                // end 68000 bus cycle
                // wait for cycleEndState == S2
                if(cycleEndState == S2) busState <= S0;
                else busState <= S3;
            end
            S4 : begin
                // 6800 bus cycle state 1
                // wait for E clock = 0
                if(pdsClockE == 0) busState <= S5;
                else busState <= S4;
            end
            S5 : begin
                // 6800 bus cycle state 2
                // wait for E clock = 1
                if(pdsClockE == 1) busState <= S6;
                else busState <= S5;
            end
            S6 : begin
                // 6800 bus cycle state 3
                // progress immediately
                busState <= S7;
            end
            S7 : begin
                // 6800 bus cycle state 4
                // progress immediately
                busState <= S8;
            end
            S8 : begin
                // 6800 bus cycle state 5
                // wait for cycleEndState == S2
                if(cycleEndState == S2) busState <= S0;
                else busState <= S8;
            end
            default: begin
                // how did we end up here?
                busState <= S0;
            end
        endcase
    end
end

// 68030 bus termination state machine
// drives CPU DSACKx signals
// synchronous to CPU clock
always @(posedge cpuClock or negedge npdsReset) begin
    if(npdsReset == 0) termState <= S0;
    else begin
        case(termState)
            S0 : begin
                // idle, wait for busState
                if(busState == S3 && pdsC8m == 1) termState <= S1;
                else if(busState == S8 && pdsC8m == 1) termState <= S1;
                else termState <= S0;
            end
            S1 : begin
                // assert 68030 bus termination
                // progress immediately
                termState <= S2;
            end
            S2 : begin
                // wait for busState
                if(busState == S0) termState <= S0;
                else termState <= S2;
            end
            default: begin
                // how did we end up here?
                termState <= S0;
            end
        endcase
    end
end
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

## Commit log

2021-03-22 Syntax fixes, added CIIN
    [paste.sv]
2021-03-25 Initial BOM
    [SE-Exp30_BOM.csv]
2021-03-25 Initial schematic and board
    [SE-Exp30.brd, SE-Exp30.sch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]
2021-03-25 Add Schematic pdf
2021-07-04 BOM Correction
    [SE-Exp30_BOM.csv]
